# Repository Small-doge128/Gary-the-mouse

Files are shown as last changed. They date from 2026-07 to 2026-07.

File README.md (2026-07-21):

# about
A custom mouse that's small and lightweight like a cookie, a little inspiration is from the zero mouse. It's my second using kicad, but it still took a lot of time. Also i used [this repository](https://github.com/badjeff/paw3395-pcb) for the sensor pcb.

# features
A powerful microcontroller with bluetooth and usb-c for charging the lipo battery, nice scroll wheel encoder, optical sensor with up to 12 000 dpi which is low power and sometimes used for gaming and four small micro switches, two for main and other two for the side buttons, you can map them however you want. Last but really good is a build in LED in the microcontroller that is the normal red, yellow and green

# step by step tutorial for firmware
1 - download the file called firmware.uF2   
2 - connect your seeed studio via usb-c                                                                                                                                               
3 - put it into bootloader mode (double tap the **RESET** button the build in led shall start pulsing).                                                                                 
4 - now open your file manager and you should see a new USB drive called `XIAO-BLE`     
5 - drag and drop the file we installed earlier into it and the USB drive should dissaper which means **good** now it shloud work **enjoy**

# dimensions
pcb - 49.5 mm and 50 mm

# why did i create it
My mouse is not that bad, but my felt that it was heavy and actually when I take the top cover off It's more comfortable. I did weanted to spice it up with my preferences, so It's more like my mouse then a customer mouse and I know I had the skills to make that, but still I've learnt a lot.

# pictures
2026-06-29-114429_hyprshot

WhatsApp Image 2026-06-11 at 17 54 53



2026-06-29-114401_hyprshot

2026-05-31-174938_hyprshot

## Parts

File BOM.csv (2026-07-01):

Name | Purpose | Qty | Total (USD) | Distributor | Link
TTC Mouse Encoder (Silver Core, 8mm) | Scroll wheel scroll detection | 1 | 6.58 | AliExpress | https://www.aliexpress.com/item/1005006514957582.html
Seeed Studio XIAO BLE nRF52840 | Main microcontroller and wireless chip for the mouse | 1 | 13.03 | AliExpress | https://www.aliexpress.com/item/1005006988954136.html
3.7V 400mAh LiPo Battery | Wireless power source for the mouse | 1 | 4.88 | AliExpress | https://www.aliexpress.com/item/1005007103616809.html
Kailh GM 8.0 Micro Switch (2pcs) | Main left and right click switches | 1 | 1.47 | AliExpress | https://www.aliexpress.com/item/1005007883133457.html
Kailh GM 8.0 Micro Switch (3pcs) | Side buttons and a extra switch | 1 | 1.94 | AliExpress | https://www.aliexpress.com/item/1005007883133457.html
PixArt PAW3395 Sensor + LM19-LSI Lens Kit | High-performance optical tracking sensor and matching lens | 1 | 11.97 | AliExpress | https://www.aliexpress.com/item/1005006293449301.html
Custom Main Mouse PCB (gerber drill files_Y7) | Main board hosting the MCU and switches (White Solder Mask) | 5 | 4.0 | JLCPCB | https://jlcpcb.com
Custom Sensor breakout PCB (gerbers_Y6) | Breakout board for the PAW3395 sensor (White Solder Mask) | 5 | 2.1 | JLCPCB | https://jlcpcb.com
C96446 (10uF ±20% 25V Ceramic Capacitor) | Decoupling/Filter Capacitor | 20 | 1.29 | LCSC | https://www.lcsc.com
C30197477 (TLV74318PDBVR-MS Linear Voltage Regulator IC) | 1.8V Voltage Regulator for Sensor Power Rail | 5 | 0.46 | LCSC | https://www.lcsc.com
C86295 (22uF ±20% 10V Ceramic Capacitor) | Decoupling/Filter Capacitor | 10 | 0.78 | LCSC | https://www.lcsc.com
C4241878 (MCT0603MD2004BP500 2MΩ Thin Film Resistor) | Pull-up/Pull-down Resistor | 5 | 0.43 | LCSC | https://www.lcsc.com
C313771 (CRCW06034R70FKEAHP 4.7Ω Thick Film Resistor) | Current Limiting / Filter Resistor | 5 | 0.52 | LCSC | https://www.lcsc.com
C51412 (CL10A335KP8NNNC 3.3uF ±10% 10V Ceramic Capacitor) | Decoupling/Filter Capacitor | 10 | 0.31 | LCSC | https://www.lcsc.com
C161117 (GCJ188R72A104KA01D 100nF ±10% 100V Ceramic Capacitor) | Decoupling/Filter Capacitor | 20 | 0.87 | LCSC | https://www.lcsc.com
C92759 (EMK107B7105KA-T 1uF ±10% 16V Ceramic Capacitor X7R) | Decoupling/Filter Capacitor | 20 | 0.65 | LCSC | https://www.lcsc.com
C394535 (PTFR0603B10K0N9 10kΩ 100V Thin Film Resistor) | Pull-up/Pull-down Resistor | 5 | 0.77 | LCSC | https://www.lcsc.com
Combined Shipping Fees | AliExpress ($19.23), JLCPCB ($1.50), LCSC Shipping ($9.65), LCSC Handling ($3) |  | 33.38
TOTAL (Base Merchandise) |  |  | 52.05
GRAND TOTAL (All Items + All Shipping + VAT) |  |  | 85.43

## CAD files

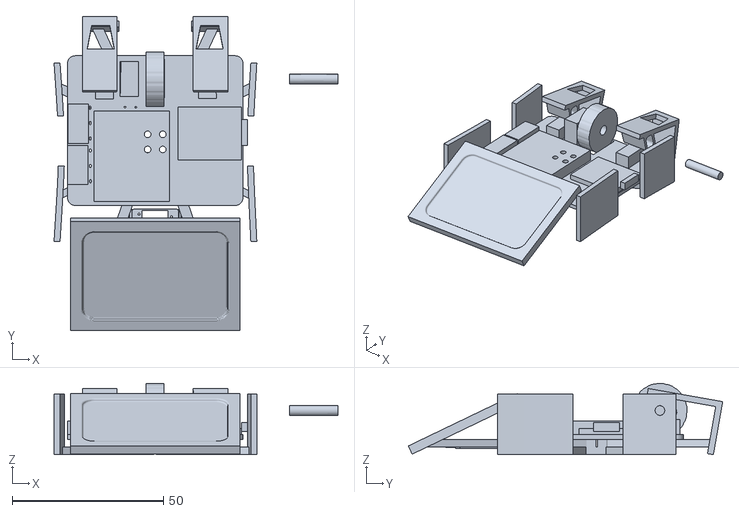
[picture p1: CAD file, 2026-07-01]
gary the mouse stl/gary the mouse shorter version.stl
93.9 x 104.0 x 23.6

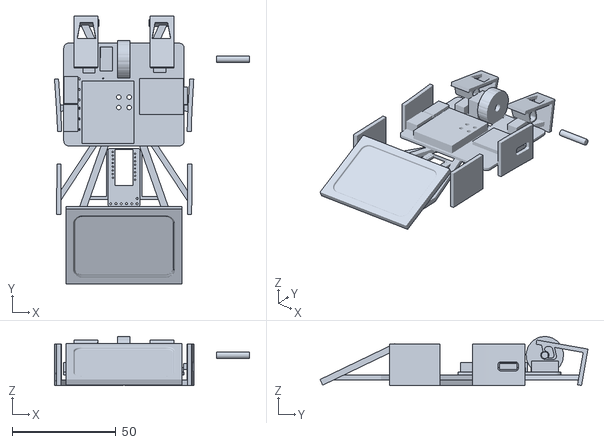
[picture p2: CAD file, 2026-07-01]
gary the mouse stl/gary the mouse long version.stl
93.9 x 129.0 x 23.6

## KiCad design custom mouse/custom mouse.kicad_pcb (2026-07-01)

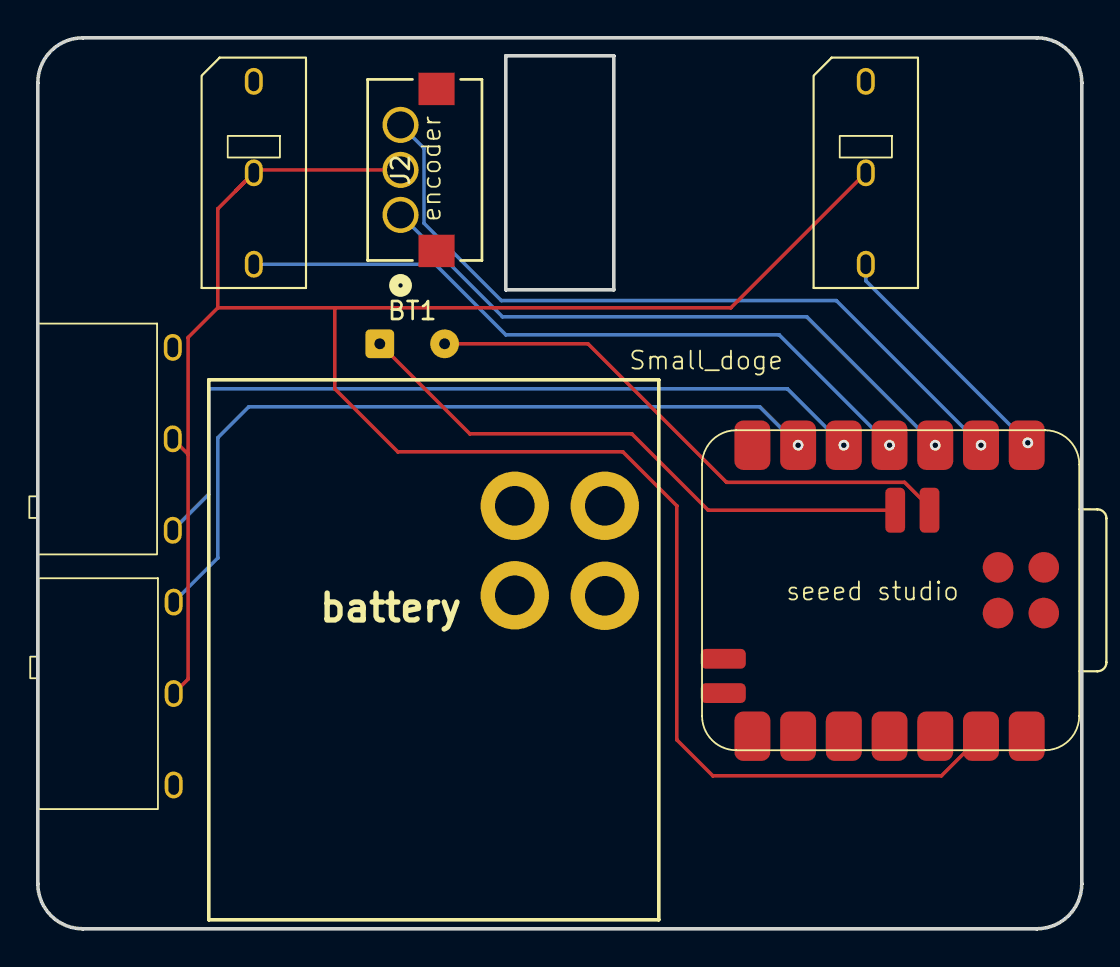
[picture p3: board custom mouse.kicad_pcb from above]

Board: 2 copper layers, 58.0 x 49.5 mm, 11 parts (0 on the bottom side), 9 nets.

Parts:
BT1: Battery_Cell; SolderWire-0.1sqmm_1x02_P3.6mm_D0.4mm_OD1mm
H1, H2, H3, H4: MountingHole; MountingHole_2.2mm_M2_DIN965_Pad
J2: EC10E1220501; CONN03_EC10E_9P8X6P1_ALPS
SW6, SW7: SW_Push_SPDT; KailhSw
SW8, SW9: SW_Push_SPDT; KailhSw sidemount
U1: XIAO-nRF52840-DIP; XIAO-nRF52840-SMD

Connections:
/pin 1: SW6.3 (C), U1.1 (P0.02_A0_D0)
/pin 2: J2.3, U1.2 (P0.03_A1_D1)
/pin 3: J2.1, U1.3 (P0.28_A2_D2)
/pin 4: SW7.3 (C), U1.4 (P0.29_A3_D3)
/pin 5: SW8.3 (C), U1.5 (P0.04_A4_D4_SDA)
/pin 6: SW9.1 (A), U1.6 (P0.05_A5_D5_SCL)
unnamed: BT1.1 (+), U1.hy
unnamed: BT1.2 (-), U1.20
unnamed: J2.2, SW6.2 (B), SW7.2 (B), SW8.2 (B), SW9.2 (B), U1.13 (GND)

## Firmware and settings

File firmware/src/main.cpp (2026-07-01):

#include <Arduino.h>
#include <Adafruit_TinyUSB.h>
#include <SPI.h>


const int leftButtonPin = 2;
const int rightButtonPin = 1;
const int backButtonPin = 4;
const int frontButtonPin = 3;
const int batteryPin = A0;
const int encoderAPin = 5;
const int encoderBPin = 6;
 const int ledRedPin = 26;
 const int ledGreenPin = 30;
 const int sensorCSPin = 10;
 const int sensorRstPin = 9;
 const int sensorMotPin = 8;

int lastA = HIGH;


uint8_t const desc_hid_report[] = { TUD_HID_REPORT_DESC_MOUSE() };
Adafruit_USBD_HID usb_hid;

const float LOW_BATTERY_V = 3.4;
const float DIVIDER_RATIO = 2.0;

float readBatteryVoltage() {
    uint32_t sum = 0;
    for (int i = 0; i < 16; i++) {
        sum += analogRead (batteryPin);
        delay(2);  
    }
    float raw = sum  / 16.0f;
    float vout = raw * (3.3/4095.0);
    return vout * DIVIDER_RATIO;
}


void setColor(bool r, bool g) {
    digitalWrite(ledRedPin, r ? LOW : HIGH);
    digitalWrite(ledGreenPin, g ? LOW : HIGH);
}


void showBatteryColor(float vbatt) {
    if (vbatt > 3.9) setColor(false, true);
    else if (vbatt > 3.6) setColor (true, true);
    else if (vbatt > 3.4) setColor (true, false);
    else setColor(false, false);
}
void pawSelect() {digitalWrite(sensorCSPin, LOW); }
void pawDeselect() {digitalWrite(sensorCSPin, HIGH); }
void pawWriteReg(uint8_t reg, uint8_t val) {
    pawSelect();
    SPI.transfer(reg | 0x80);
    SPI.transfer(val);
    pawDeselect();
}
void readPAW3395Motion(int &dx, int &dy) {
    dx = 0;
    dy = 0;
}



uint8_t readMouseButtons() {
 uint8_t buttons = 0;
 if  (digitalRead(leftButtonPin) == LOW) buttons |= MOUSE_BUTTON_LEFT;
 if  (digitalRead(rightButtonPin) == LOW)buttons |= MOUSE_BUTTON_RIGHT;
 if  (digitalRead(backButtonPin) == LOW)buttons |= MOUSE_BUTTON_BACKWARD;
 if  (digitalRead(frontButtonPin) == LOW)buttons |= MOUSE_BUTTON_FORWARD;
 return buttons;
}

uint8_t pawReadReg(uint8_t reg) {
    pawSelect();
    SPI.transfer(reg & 0x7f);
    delayMicroseconds(1);
    uint8_t val = SPI.transfer(0x00);
    pawDeselect();
    return val;
}


void setup() {


//*************microswitches****************
 pinMode(leftButtonPin, INPUT_PULLUP);
 pinMode(rightButtonPin, INPUT_PULLUP);
 pinMode(backButtonPin, INPUT_PULLUP);
 pinMode(frontButtonPin, INPUT_PULLUP);
 pinMode(batteryPin, INPUT);
  pinMode(ledRedPin, OUTPUT);
  pinMode(ledGreenPin, OUTPUT);
  pinMode(sensorCSPin, OUTPUT);
  pinMode(sensorRstPin, OUTPUT);
  pinMode(sensorMotPin, INPUT_PULLUP);

//for sensor
digitalWrite(sensorCSPin, HIGH);
digitalWrite(sensorRstPin, HIGH);
SPI.begin();
 
usb_hid.setPollInterval(2);
usb_hid.setReportDescriptor(desc_hid_report, sizeof(desc_hid_report));
usb_hid.begin();

//for TTC encoder
Serial.begin (115200);

while (!TinyUSBDevice.mounted()) delay(1);

//*************TTC encoder******************

pinMode(encoderAPin, INPUT_PULLUP);
pinMode(encoderBPin, INPUT_PULLUP);
lastA = digitalRead(encoderAPin);

//***************build in LED***************
digitalWrite(ledRedPin, HIGH);
digitalWrite(ledGreenPin, HIGH);

}




void loop() {

if (!TinyUSBDevice.mounted()) return;
 //*************battery*********************
float vbatt = readBatteryVoltage();
showBatteryColor(vbatt);

if (vbatt <LOW_BATTERY_V) {
 usb_hid.mouseReport(0, 0, 0, 0, 0, 0);
 delay(500);
 return;
}

//****************sensor********************
int dx = 0;
int dy = 0;
readPAW3395Motion(dx, dy);
usb_hid.mouseReport(0, readMouseButtons(), dx, dy, 0, 0);

//*************TTC encoder******************
 int a = digitalRead(encoderAPin);
 int b = digitalRead(encoderBPin);

 if (a != lastA) {
    if (a == LOW) {
        if (b ==HIGH) {
          usb_hid.mouseScroll(0, 1, 0);
        }else{
            usb_hid.mouseScroll(0, -1, 0);
        }
    }
    lastA = a;
  }
}

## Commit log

2026-07-16 Rename gary the mouse long version stl.stl to gary the mouse long version .stl
    [gary the mouse long version .stl]
2026-07-16 Rename gary the mouse shorter version stl.stl to gary the mouse shorter version.stl
    [gary the mouse shorter version.stl]
2026-07-16 Rename gary the mouse long version .stl to gary the mouse long version.stl
    [gary the mouse long version.stl]
